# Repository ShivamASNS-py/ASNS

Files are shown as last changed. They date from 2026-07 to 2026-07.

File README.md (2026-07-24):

<div align="center">
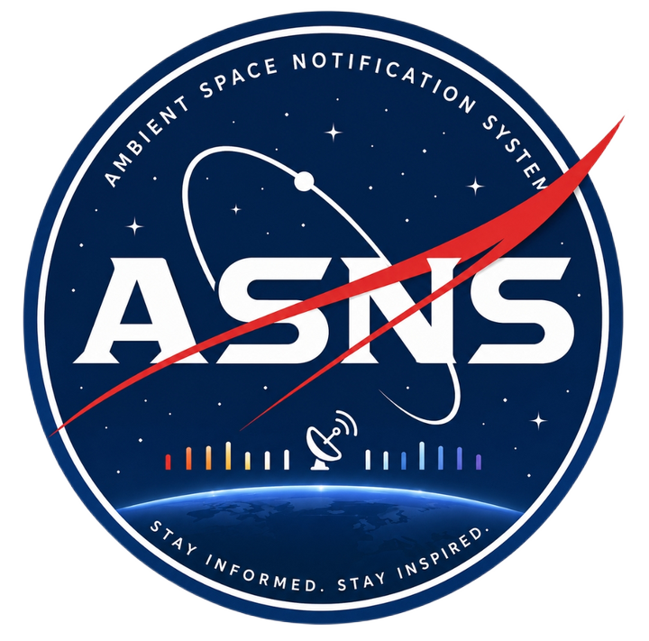
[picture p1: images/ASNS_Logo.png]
ASNS Logo
  

  # Ambient Space Notification System (ASNS)

  ### Stay informed. Stay inspired.
</div>

Ever been sitting at your desk and wondered what's happening in space right now? Most of us don't check NASA's website every hour — and if you do, that's honestly impressive.

ASNS is a desk companion that quietly keeps you connected to space. A wall-mounted LED strip runs subtle ambient lighting behind your desk, and shifts into short notification animations when something real happens — a solar flare, an ISS pass overhead, a shift in Earth's weather systems. No app to check, no feed to scroll. Just a glance at your wall.

A compact control unit sits on the desk — a 3D-printed, rounded 11.7 × 10.5 × 6 cm box housing the brains of the system, connected to the LED strip via JST connectors.

## How it works

- **ESP32-WROVER-IE** polls **Nova**, the AI backend, over HTTPS for space event data.
- **Nova** (built on Groq's `gpt-oss-120b`) pulls from NASA (DONKI, EONET), N2YO (live satellite/ISS telemetry), and Le Système Solaire (planetary data), then decides what's actually worth surfacing — since raw satellite data alone updates constantly, and without filtering it would drown out every other signal.
- A lightweight on-device filter also runs directly on the ESP32, recognizing 16 tracked satellites (ISS, Tiangong, Hubble, Terra, Aqua, and more) so simple, high-value events — like *"ISS visible in 5 minutes!"* — can trigger a notification animation without waiting on a full AI round-trip.
- To avoid free-tier cold starts on Render, the ESP32 sends a lightweight keep-alive ping roughly every 10 minutes, separate from its actual data requests (every 5 minutes).
- When nothing's happening, the **WS2812B strip** (5m, 300 LEDs) runs a user-selected ambient pattern — Deep Space, Starfield, Moonlight, Aurora, Mars Glow, Solar Wind — in warm, low-brightness tones so it's easy to leave running while working or studying.
- When something happens, the strip pauses ambient mode, plays a short notification animation for the relevant category (Mars, Earth, Moon, Sun, Saturn, Satellites), then fades back.

**Note:** the filtering logic above is implemented and live on both sides (Nova's `/sensor` endpoint and the ESP32 satellite filter) — see [Project Status](#project-status) for what's still pending on the hardware/UI side.

## Meet Nova

Nova isn't just a data pipeline — she's a warm, expressive AI with her own personality: playful and witty when you are, gentle and supportive when you're not, and unafraid to express herself with a bit of kaomoji flair. Today, she lives on Telegram, where she can hold a natural conversation, actually look at photos sent to her using Google Lens, and pull real-time space data on request — satellite telemetry, solar activity, planetary data, and image search.

She runs on Groq's `gpt-oss-120b`, exposed through a FastAPI `/chat` endpoint — the same endpoint ASNS's hardware will eventually call. Full introduction in [`backend/intro.md`](./backend/intro.md).

## Control unit

The desk unit has a 3.2" IPS display (LVGL UI) and 5 capacitive touch buttons:

 Button Function 

| ◀ | Previous (ambient color / notification) or Back |
| ● | Select / Confirm |
| ▶ | Next (ambient color / notification) |
| ☰ | Menu — Settings, Brightness, Wi-Fi, Sleep, About |
| ⌂ | Home — return to main screen instantly |

Ambient color is chosen manually from a scrollable bar of 10+ named colors (e.g. *Aurora Green*). Everything is currently user-selected rather than automatic — you choose what mode you're in.

## Hardware

Full parts list with vendors, prices, and photos in [`BOM.md`](./BOM.md).

- ESP32-WROVER-IE
- WS2812B 5V LED strip (5m, 60 LEDs/m — 300 LEDs)
- WaveShare 3.2" HDMI IPS Display
- TTP223 capacitive touch sensors (×5 active, extras as spares)
- 74AHCT125 logic level shifter
- Mini-360 buck converters
- 5V/10A SMPS (dedicated LED power rail, separate from control unit power)
- Supporting passives (capacitors, resistors, JST connectors)

Enclosure is 3D printed (material TBD — likely PLA or acrylic-finish print), designed to sit unobtrusively on a desk. Wiring diagrams and enclosure sketches/renders are in [`hardware/`](./hardware/).

## Software

- **Firmware** (`/firmware`) — ESP32 C++ code. Networking + filtering skeleton is built: WiFi connection/reconnect handling, a keep-alive ping to Nova every 10 minutes (prevents Render cold-starts), a data-request timer every 5 minutes, and a working on-device satellite filter — checks N2YO visual pass data against elevation, magnitude, and duration thresholds for a priority-ordered list of 16 tracked satellites (ISS, Tiangong, Hubble, Terra, Aqua, and more), with its own daily notification cap kept separate from the AI-side budget. Nova's `/sensor` endpoint (below) is ready on the backend side; still pending on firmware: LED strip driving and LVGL display/touch UI.
- **Backend** (`/backend`) — Nova, the AI layer. Python, built on Groq's `gpt-oss-120b`, deployed as a web service on Render (free tier). A fully working Telegram-based conversational AI with tool-calling (image search, satellite telemetry, solar weather, planetary data, Earth events via EONET) and image vision, plus a live `/chat` API endpoint. A second, fully separate `/sensor` endpoint handles the actual notification logic: given a category (Sun, Earth, Mars, Moon, Saturn), it pulls the relevant live data and runs it through a stateless significance filter with real per-category rules — e.g. Sun only notifies for M-class-or-above flares or Earth-directed CMEs, Moon only on phase transitions, Mars/Saturn on essentially any new event. This filter is fully isolated from Nova's chat personality and fails safe (no notification) if anything errors.

## APIs used

| API | Purpose |

| Groq (`gpt-oss-120b`) | Core reasoning / conversational brain |

| NASA (DONKI, EONET) | Solar activity, Earth events |

| N2YO | Live satellite/ISS telemetry, real-time position |

| Serper (Google Images) | Image search for Nova's responses |

| SerpAPI (Google Lens) | Vision — lets Nova actually see and identify photos sent to her |

| Le Système Solaire | Static planetary data (gravity, mass, moons) — requires a free API key |

## Project Status

- ✅ **Backend (Nova)** — conversational AI, tool-calling, image vision, `/chat` endpoint, and the AI event-filtering `/sensor` endpoint all working and live on Render
- 🔧 **Firmware** — networking + on-device satellite filter skeleton complete (WiFi handling, Nova keep-alive/data timers, N2YO visual-pass filtering with priority list and daily cap); LED strip driving and LVGL display/touch UI still pending
- 🔧 **Hardware** — wiring diagrams and enclosure design in progress
- 🔧 **UI/UX** — LVGL implementation pending

## Want to talk to Nova?

Nova is live right now. If you'd like to chat with her directly — ask her about a satellite overhead, the Sun's current mood, or just say hi — reach out and I can add you to her access list. Seeing her personality in action tells you more about this project than any README section could.

---

*Built by a 15-year-old learning PCB design, embedded programming, API integration, AI, and product design — one debug session at a time. Submitted for the Hack Club Macondo grant.*

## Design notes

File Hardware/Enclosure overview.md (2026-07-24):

# ASNS Enclosure Overview
This enclosure is designed for the Ambient Space Notification System (ASNS) and is intended to house an ESP32-WROVER-IE, 3.5" SPI display, WS2812 LED control electronics, TTP223 touch sensors, buck converter, level shifter, and supporting components. The current CAD model already includes the overall enclosure dimensions, display opening, DC jack opening, ventilation, and general external design.

Some internal mechanical features are intentionally left for professional customization. These include the removable rear cover, screw bosses, display mounting posts, ESP32 standoffs, component mounting features, cable management, and any print-specific tolerances. Please optimize these features based on the actual component dimensions, recommended manufacturing practices, and the chosen printing material (preferably PETG).

The final enclosure should prioritize easy assembly, serviceability, structural strength, and clean cable routing while preserving the existing external appearance and dimensions.

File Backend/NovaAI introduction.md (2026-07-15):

# Nova

Nova is the AI mind behind ASNS — but she's not just a data pipeline. She's a warm, expressive conversational AI with her own personality: playful and witty when you are, gentle and supportive when you're not, and unafraid to express herself with a bit of kaomoji flair (⁄ ⁄>⁄ ▽ ⁄<⁄ ⁄). Right now, Nova lives on Telegram, where she can chat naturally, analyze photos you send her, and pull real-time space data on request — live satellite telemetry (N2YO), solar activity (NASA DONKI), and planetary physical data (Le Système Solaire), plus image search for anything you're curious about.
She runs on Groq's gpt-oss-120b, exposed through a FastAPI /chat endpoint — the same endpoint ASNS's hardware will eventually call. The next phase of her development is what makes ASNS possible: teaching her to proactively watch space data instead of only responding when asked, and to decide what's actually worth a notification versus background noise.

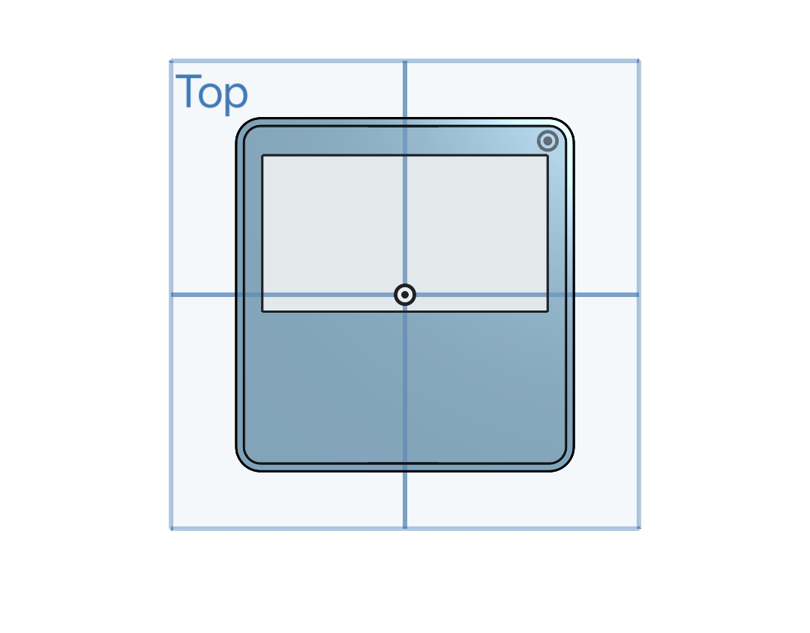
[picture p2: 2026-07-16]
Hardware/Top.jpg

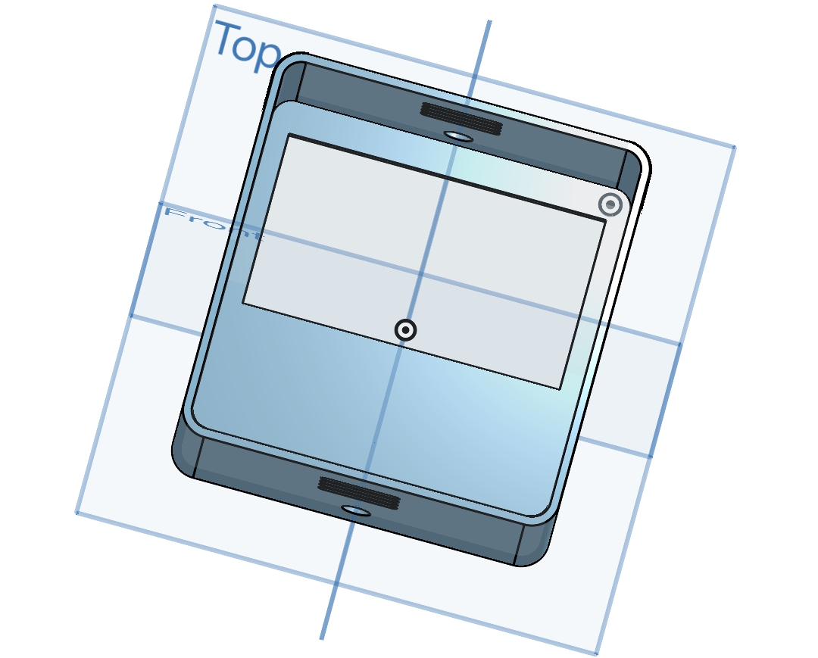
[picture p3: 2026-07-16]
Hardware/multiple sides.jpg

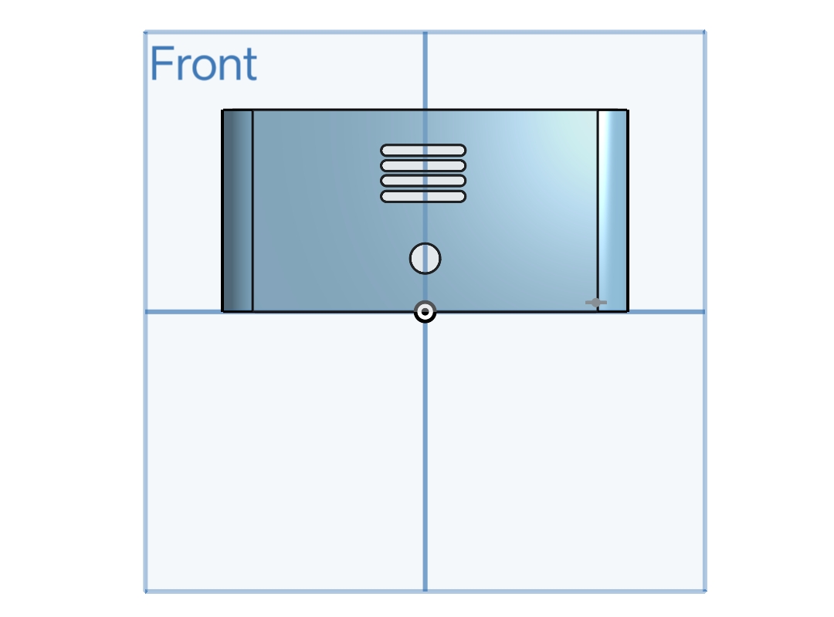
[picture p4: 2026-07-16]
Hardware/Back.jpg

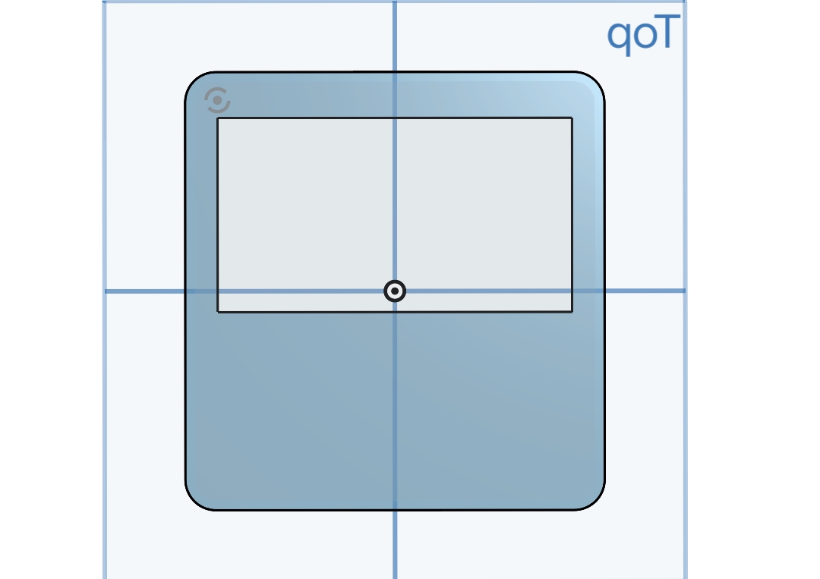
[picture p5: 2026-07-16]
Hardware/Bottom.jpg

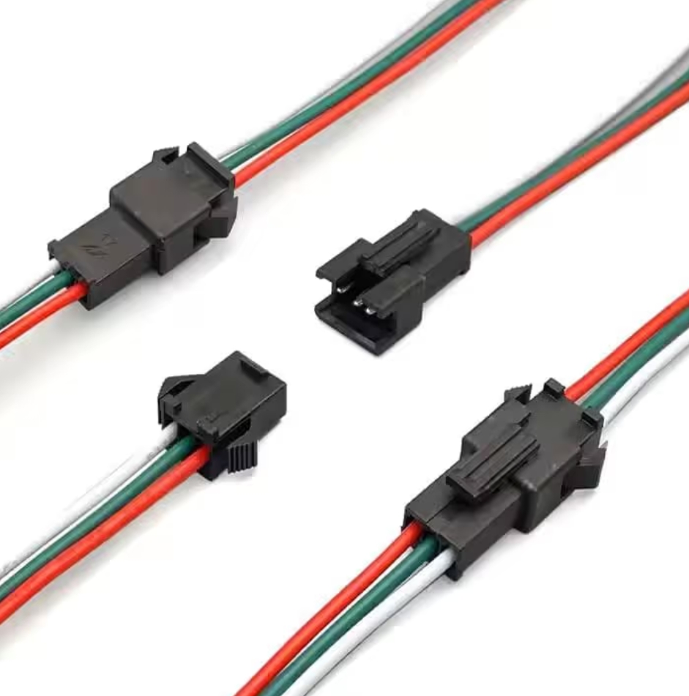
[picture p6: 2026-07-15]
images/JST_connectors.jpg

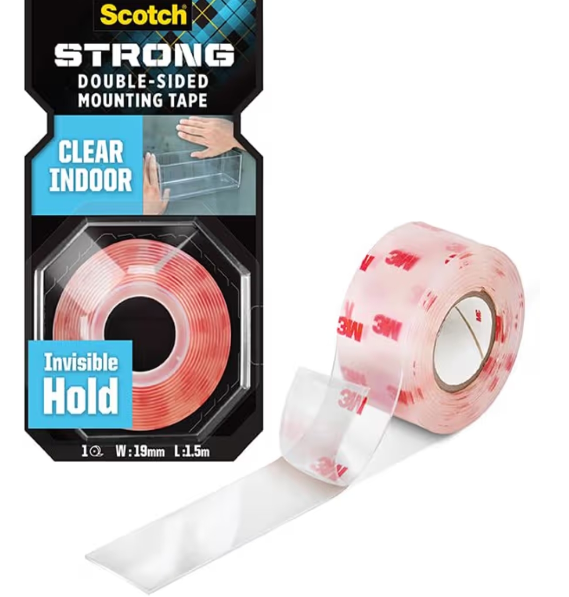
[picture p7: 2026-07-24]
images/Scotch_double_sided_tape.jpg

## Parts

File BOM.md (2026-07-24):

### ESP32-WROVER-IE
 - Type: Microcontroller
 - Quantity: 1
 - Vendor: amazon.in
 - Price: ₹2,900
 - Image: [ESP32-WROVER-IE.jpg](images/ESP32-WROVER-IE.jpg)

### WS2812B (5V, 5m, 60 LEDs/m — 300 LEDs)
 - Type: Addressable RGB LED Strip
 - Quantity: 5m
 - Vendor: amazon.in
 - Price: ₹2,296
 - Image: [WS2812B.jpg](images/WS2812B.jpg)
   
### 3.5" SPI TFT ILI9488 Display 
 - Type: Display
 - Quantity: 1
 - Vendor: amazon.in
 - Price: ₹1,374
 - Image: [TFT_SPI_PANEL](images/TFT_SPI_PANEL.jpg)
   
### Logic Level Shifter (SN74AHCT125N)
 - Type: Logic Level Shifter
 - Quantity: 3
 - Vendor: robu.in
 - Price: ₹80
 - Image: [Logic level shifters](images/Logic%20level%20shifters.jpg)
   
### Capacitor 1000µF / 6.3V (Electrolytic)
 - Type: Capacitor
 - Quantity: 3 (pack of 10)
 - Vendor: amazon.in
 - Price: ₹74
 - Image: [Capacitors.jpg](images/Capacitors.jpg)
   
### Touch Sensors / TTP223
 - Type: Capacitive Touch Sensor
 - Quantity: 8
 - Vendor: amazon.in
 - Price: ₹170
 - Image: [TTP223 touch pads](images/TTP223%20touch%20pads.jpeg)
   
### Power Converter Mini-360 Buck
 - Type: Buck Converter
 - Quantity: 2
 - Vendor: robocraze
 - Price: ₹244
 - Image: [Mini buck](images/Mini%20buck.jpg)
   
### Resistor 330Ω
 - Type: Resistor
 - Quantity: 1 pack (10)
 - Vendor: robocraze
 - Price: ₹13
 - Image: [Resistor's 330 ohms](images/Resistor's%20330%20ohms.jpg)
   
### 5V 10A SMPS (LED Power Supply)
 - Type: Power Supply (barrel jack)
 - Quantity: 1
 - Vendor: amazon.in
 - Price: ₹799
 - Image: [SMPS.jpg](images/SMPS.jpg)

### Female DC connector
 - Type: Connector
 - Quantity: pack of 3 available only
 - Vendor: amazon.in
 - Price: ₹93
 - Image: [Female_DC_Connectors](images/Female_DC_Connectors.jpg)

### JST connector Female 3-pin
 - Type: Connector
 - Quantity: pair
 - Vendor: amazon.in
 - Price: ₹39
 - Image: [JST_connectors](images/JST_connectors.jpg)

### JST connector SM 2-pin
 - Type: Connector
 - Quantity: pair
 - Vendor: amazon.in
 - Price: ₹39
 - Image: [2pin_JST_connectors](images/2pin_JST_connectors)

### 26AWG wires
 - Type: Wiring 
 - Quantity: Kit(6 colors, 5ft/each)
 - Vendor: amazon.in
 - Price: ₹1,939
 - Image: [26AWG_wires](images/26AWG_wires.jpg)

### 18AWG wires
 - Type: Wiring
 - Quantity: 1
 - Vendor: amazon.in
 - Price: ₹699
 - Image: [18AWG_wires](images/18AWG_wires.jpg)

### Double sided tape
 - Type: Adhesive 
 - Quantity: 1
 - Vendor: amazon.in
 - Price: ₹185
 - Image: [Scotch_double_sided_tape](images/Scotch_double_sided_tape.jpg)

### 2mm 2.5mm 3mm screws
 - Type: Hardware 
 - Quantity: pair
 - Vendor: amazon.in
 - Price: ₹409
 - Image: [screws](images/screws.jpg)

### Perfboards 
 - Type: Prototyping boards
 - Quantity: pack of 5
 - Vendor: amazon.in
 - Price: ₹324
 - Image: [Perfboard](images/Perfboard.jpg)

### 3D design/Enclosure 
 - Type: Enclosure 
 - Quantity: 1
 - Vendor: Champ3d
 - Price: ₹2,874

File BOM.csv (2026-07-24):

Part | Type | Quantity | Vendor | Price (INR) | Purchase Link | Image
ESP32-WROVER-IE | Microcontroller | 1 | amazon.in | 2900 | https://amzn.in/d/06A1Ebtr | images/ESP32-WROVER-IE.jpg
WS2812B LED Strip (5V 5m 60LEDs/m) | Addressable RGB LED Strip | 5m | amazon.in | 2296 | https://amzn.in/d/05Zo8QYw | images/WS2812B.jpg
3.5" SPI TFT ILI9488 Display | Display | 1 | amazon.in | 1374 | https://amzn.in/d/03nC11ro | images/TFT_SPI_PANEL.jpg
Logic Level Shifter (SN74AHCT125N) | Logic Level Shifter | 3 | robu.in | 80 | https://robu.in/product/sn74ahct125n-texas-instruments-8ma-1-4-5v5-5v-8ma-4-dip-14-buffers-drivers-receivers-transceivers-rohs/ | images/Logic level shifters.jpg
Capacitor 1000uF/6.3V | Capacitor | 3 (pack of 10) | amazon.in | 74 | https://amzn.in/d/05uHUVZS | images/Capacitors.jpg
Touch Sensors / TTP223 | Capacitive Touch Sensor | 8 | amazon.in | 170 | https://amzn.in/d/04g2vz6i | images/TTP223 touch pads.jpeg
Mini-360 Buck Converter | Buck Converter | 2 | robocraze | 244 | https://amzn.in/d/06xOWHJF | images/Mini buck.jpg
Resistor 330 ohm | Resistor | 1 pack (10) | robocraze | 13 | https://robocraze.com/products/330-ohm-resistor-pack-of-10 | images/Resistor's 330 ohms.jpg
5V 10A SMPS | Power Supply (barrel jack) | 1 | amazon.in | 799 | https://amzn.in/d/0dAPRK4r | images/SMPS.jpg
Female DC Connector | Connector | pack of 3 | amazon.in | 93 | https://amzn.in/d/04QIgEz6 | images/Female_DC_Connectors.jpg
JST Connector Female 3-pin | Connector | pair | amazon.in | 39 | https://amzn.in/d/04YqUnBA | images/JST_connectors.jpg
JST Connector SM 2-pin | Connector | pair | amazon.in | 39 | https://amzn.in/d/01EoEE3r | images/2pin_JST_connectors.jpg
26AWG Wires | Wiring | Kit (6 colors 5ft/each) | amazon.in | 1939 | https://amzn.in/d/01uHemKc | images/26AWG_wires.jpg
18AWG Wires | Wiring | 1 | amazon.in | 699 | https://amzn.in/d/053Ct0r4 | images/18AWG_wires.jpg
Double Sided Tape | Adhesive | 1 | amazon.in | 185 | https://amzn.in/d/07rVsG24 | images/Scotch_double_sided_tape.jpg
Screws (2mm 2.5mm 3mm) | Hardware | pair | amazon.in | 409 | https://amzn.in/d/07mqGfzi | images/screws.jpg
Perfboards | Prototyping Boards | pack of 5 | amazon.in | 324 | https://amzn.in/d/08b6Tsvi | images/Perfboard.jpg
3D Enclosure | Enclosure | 1 | Champ3D.in | 2 | 874

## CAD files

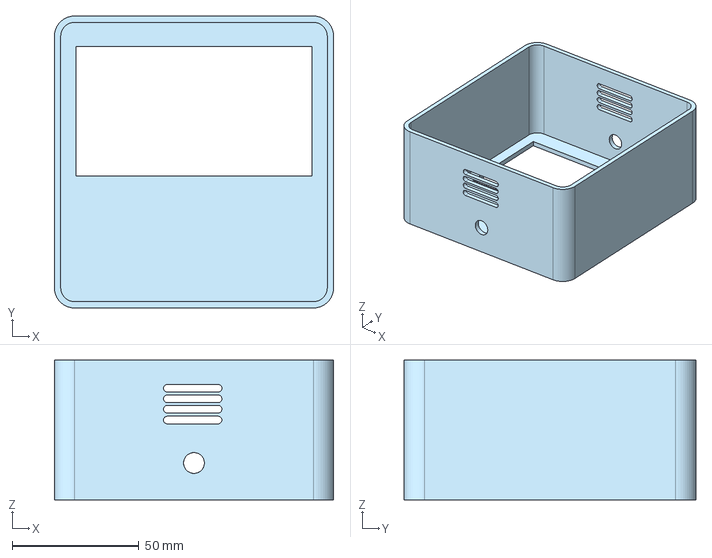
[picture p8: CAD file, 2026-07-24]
ASNS.step
110.0 x 115.0 x 55.0 mm

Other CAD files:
Hardware/ASNS enclosure.step

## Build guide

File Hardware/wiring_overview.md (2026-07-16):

## Wiring Diagram

The full wiring diagram (`Wiring_Diagram.png`) covers the complete electrical setup for the ASNS control unit, including:

1. **Power input** — 5V 10A SMPS feeding the system via JST connector
2. **Buck converter** — Mini-360 DC-DC converter providing a stable 5V rail
3. **Power distribution** — 5V/GND bus feeding the ESP32, display, level shifter, touch sensors, and LED output capacitor
4. **Display** — 3.5" SPI TFT (ILI9488) connected directly to ESP32 GPIOs
5. **Level shifter & LED output** — 74AHCT125 stepping the ESP32's data line up for the WS2812B strip, plus a smoothing capacitor near the LED output connector
6. **LED strip power injection** — dual injection points (start and far end of the 5m strip) to prevent voltage drop across the run
7. **GPIO pin summary** — full mapping of ESP32 pins to display, touch sensors, and LED data
8. **JST connector pinouts** — power input and LED strip output
9. **General wiring notes** — common grounding, wire gauge, and brightness-limiting guidance

This diagram was AI-generated based on my BOM and finalized pin assignments, since I don't have access to diagramming software on mobile as I'm away from my laptop. I reviewed it against my actual components and confirmed it matches the hardware I'm using.

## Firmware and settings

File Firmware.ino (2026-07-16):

#include <WiFi.h>
#include <HTTPClient.h>
#include <WiFiClientSecure.h>
#include <ArduinoJson.h>
#include <time.h>
#include "secrets.h"

const char* WIFI_SSID     = WIFI_SSID_SECRET;
const char* WIFI_PASSWORD = WIFI_PASSWORD_SECRET;

const char* NOVA_BASE_URL   = NOVA_BASE_URL_SECRET;
const char* NOVA_PING_PATH  = "/";
const char* NOVA_SENSOR_PATH = "/sensor";

const char* N2YO_API_KEY = N2YO_API_KEY_SECRET;
const double OBSERVER_LAT = OBSERVER_LAT_SECRET;
const double OBSERVER_LNG = OBSERVER_LNG_SECRET;
const double OBSERVER_ALT = OBSERVER_ALT_SECRET;

const unsigned long PING_INTERVAL_MS = 10UL * 60UL * 1000UL;
const unsigned long ASK_INTERVAL_MS  = 5UL  * 60UL * 1000UL;
const unsigned long SAT_CHECK_INTERVAL_MS = 5UL * 60UL * 1000UL;

unsigned long lastPingTime = 0;
unsigned long lastAskTime  = 0;
unsigned long lastSatCheckTime = 0;

const char* SENSOR_CATEGORIES[] = { "sun", "earth", "mars", "moon", "saturn" };
const int NUM_SENSOR_CATEGORIES = sizeof(SENSOR_CATEGORIES) / sizeof(SENSOR_CATEGORIES[0]);
int nextCategoryIndex = 0;

struct TrackedSatellite {
  int noradId;
  const char* name;
  int priority;
};

TrackedSatellite trackedSats[] = {
  {25544, "ISS",         1},
  {48274, "Tiangong",    2},
  {20580, "Hubble",      3},
  {25994, "Terra",       4},
  {27424, "Aqua",        5},
  {27386, "Envisat",     6},
  {33591, "NOAA 19",     7},
  {28654, "NOAA 18",     8},
  {39084, "Landsat 8",   9},
  {49260, "Landsat 9",   10},
  {39634, "Sentinel-1A", 11},
  {40697, "Sentinel-2A", 12},
  {36585, "NAVSTAR 65 (USA 213)", 13},
  {44637, "TJS-4",       14},
  {22219, "Cosmos 2219", 15},
  {44932, "Starlink",    16},
};
const int NUM_TRACKED_SATS = sizeof(trackedSats) / sizeof(trackedSats[0]);

const double MIN_ELEVATION_DEG = 40.0;
const double MAX_MAGNITUDE     = 3.0;
const int    MIN_DURATION_SEC  = 60;

const int MAX_SAT_NOTIFICATIONS_PER_DAY = 4;
int satNotificationsToday = 0;
int lastResetDay = -1;

const long GMT_OFFSET_SEC = 5.5 * 3600;
const int DAYLIGHT_OFFSET_SEC = 0;
const char* NTP_SERVER = "pool.ntp.org";

// ==================== SETUP ====================

void setup() {
  Serial.begin(115200);
  connectWiFi();
  configTime(GMT_OFFSET_SEC, DAYLIGHT_OFFSET_SEC, NTP_SERVER);
}

void connectWiFi() {
  Serial.print("Connecting to WiFi");
  WiFi.begin(WIFI_SSID, WIFI_PASSWORD);
  while (WiFi.status() != WL_CONNECTED) {
    delay(500);
    Serial.print(".");
  }
  Serial.println("\nWiFi connected. IP: " + WiFi.localIP().toString());
}

// ==================== MAIN LOOP ====================

void loop() {
  unsigned long now = millis();

  if (WiFi.status() != WL_CONNECTED) {
    connectWiFi();
  }

  checkMidnightReset();

  if (now - lastPingTime >= PING_INTERVAL_MS) {
    lastPingTime = now;
    pingNova();
  }

  if (now - lastAskTime >= ASK_INTERVAL_MS) {
    lastAskTime = now;
    askNova();
  }

  if (now - lastSatCheckTime >= SAT_CHECK_INTERVAL_MS) {
    lastSatCheckTime = now;
    checkSatellites();
  }

  delay(100);
}

void checkMidnightReset() {
  time_t nowEpoch;
  time(&nowEpoch);
  struct tm timeinfo;

  if (!localtime_r(&nowEpoch, &timeinfo)) return;
  if (timeinfo.tm_year + 1900 < 2020) return;

  int today = timeinfo.tm_yday;

  if (lastResetDay == -1) {
    lastResetDay = today;
    return;
  }

  if (today != lastResetDay) {
    satNotificationsToday = 0;
    lastResetDay = today;
    Serial.println("[SatFilter] Midnight rollover — daily notification cap reset");
  }
}

// ==================== NOVA: PING (keep-alive) ====================

void pingNova() {
  if (WiFi.status() != WL_CONNECTED) return;

  WiFiClientSecure client;
  client.setInsecure();

  HTTPClient http;
  String url = String(NOVA_BASE_URL) + NOVA_PING_PATH;
  http.begin(client, url);
  http.setTimeout(15000);

  int httpCode = http.GET();
  Serial.printf("[Ping] Nova status: %d\n", httpCode);
  http.end();
}

// ==================== NOVA: ASK (real data) ====================

void askNova() {
  if (WiFi.status() != WL_CONNECTED) return;

  WiFiClientSecure client;
  client.setInsecure();

  HTTPClient http;
  String url = String(NOVA_BASE_URL) + NOVA_SENSOR_PATH;
  http.begin(client, url);
  http.addHeader("Content-Type", "application/json");
  http.setTimeout(90000);

  const char* category = SENSOR_CATEGORIES[nextCategoryIndex];
  nextCategoryIndex = (nextCategoryIndex + 1) % NUM_SENSOR_CATEGORIES;

  String requestBody = "{\"category\": \"" + String(category) + "\"}";
  Serial.printf("[Ask] Requesting category: %s\n", category);

  int httpCode = http.POST(requestBody);

  if (httpCode == 200) {
    String response = http.getString();
    Serial.println("[Ask] Nova response: " + response);

    StaticJsonDocument<512> doc;
    DeserializationError err = deserializeJson(doc, response);

    if (!err) {
      bool notify = doc["notify"] | false;
      const char* priority = doc["priority"] | "low";
      const char* reason = doc["reason"] | "";

      if (notify) {
        Serial.printf("[Ask] NOTIFY - priority: %s, reason: %s\n", priority, reason);
      }
    } else {
      Serial.println("[Ask] JSON parse failed");
    }
  } else {
    Serial.printf("[Ask] Request failed, code: %d\n", httpCode);
  }

  http.end();
}

// ==================== SATELLITE FILTER (on-device, no Nova) ====================

void checkSatellites() {
  if (satNotificationsToday >= MAX_SAT_NOTIFICATIONS_PER_DAY) {
    Serial.println("[SatFilter] Daily satellite cap reached, skipping check");
    return;
  }

  if (WiFi.status() != WL_CONNECTED) return;

  for (int i = 0; i < NUM_TRACKED_SATS; i++) {
    if (satNotificationsToday >= MAX_SAT_NOTIFICATIONS_PER_DAY) break;

    bool qualifies = checkSinglePass(trackedSats[i]);
    if (qualifies) {
      satNotificationsToday++;
      Serial.printf("[SatFilter] NOTIFY - %s pass qualifies (visible)\n", trackedSats[i].name);
    }
  }
}

bool checkSinglePass(TrackedSatellite sat) {
  WiFiClientSecure client;
  client.setInsecure();

  HTTPClient http;
  String url = "https://api.n2yo.com/rest/v1/satellite/visualpasses/"
               + String(sat.noradId) + "/"
               + String(OBSERVER_LAT, 6) + "/"
               + String(OBSERVER_LNG, 6) + "/"
               + String(OBSERVER_ALT, 1) + "/"
               + "1/"
               + String(MIN_DURATION_SEC)
               + "?apiKey=" + N2YO_API_KEY;

  http.begin(client, url);
  http.setTimeout(20000);
  int httpCode = http.GET();

  bool result = false;

  if (httpCode == 200) {
    String response = http.getString();

    DynamicJsonDocument doc(4096);
    DeserializationError err = deserializeJson(doc, response);

    if (!err && doc.containsKey("passes")) {
      JsonArray passes = doc["passes"];
      for (JsonObject pass : passes) {
        double maxEl = pass["maxEl"] | 0.0;
        double mag   = pass["mag"]   | 99.0;
        int duration  = pass["duration"] | 0;

        if (maxEl >= MIN_ELEVATION_DEG && mag <= MAX_MAGNITUDE && duration >= MIN_DURATION_SEC) {
          result = true;
          break;
        }
      }
    }
  } else {
    Serial.printf("[SatFilter] N2YO request failed for %s, code: %d\n", sat.name, httpCode);
  }

  http.end();
  return result;
}

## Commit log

2026-07-12 Create BOM pictures
2026-07-16 Create enclosure
2026-07-16 Create Enclosure overview
2026-07-16 Update Enclosure overview
2026-07-16 Rename Enclosure overview to Enclosure overview.md
2026-07-24 Update Enclosure overview.md
